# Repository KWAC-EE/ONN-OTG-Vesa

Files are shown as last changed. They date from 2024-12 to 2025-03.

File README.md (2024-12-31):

# ONN-OTG-Vesa
Powered Expansion Hub for the Walmart Onn TV Box


Outputs are saved into a ZIP folder, which can be uploaded directly to JLCPCB or PCBWay

PDFs are for reference to schematics and internal layers of the PCB

Hub should be assembled as standard 4-layer 1.6mm FR4 PCBA

Vesa may be FR4 or Aluminum (used for mounting hub to back of monitor)

C-to-Micro adapter is used to bridge Hub to Onn TV-Box (provides both power & data)

Hub linked to Vesa plate with 4x of 2108-440-AL-7 (https://www.digikey.com/short/th37r9zm) and 8x #4-40 screws

Onn TV box affixed to Hub PCBA with 5cm x 5cm velcro strips (for soft alignment of adapter)

Requires developer mode through Onn Android-tv system -> Default USB -> Ethernet to use peripherals

Updates to Android/Google TV have nerfed expandible storage, so SD card success may vary

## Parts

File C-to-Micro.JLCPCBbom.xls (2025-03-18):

Comment | Designator | Footprint | JLCPCB Part #
 | J1 | USB-309GD | C309337
0 | R1 | 0603 | C21189
 | J2 | ZX80-B-5SA(30) | C598212

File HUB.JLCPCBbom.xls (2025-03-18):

Comment | Designator | Footprint | JLCPCB Part #
0.01uF | C68 | 0603 | C57112
 | D1 | DO-214AC | C264107
 | J4 | TF-01A | C91145
10pF | C104,C102 | 0603 | C1634
47K | R18 | 0603 | C25819
680 | R11 | 0603 | C23228
 | J3 | 907-111A1022D10200 | C12049
0.1uF | C76,C75,C71,C70,C69,C41,C40,C39,C34,C33,C29,C28,C23,C20,C17,C16,C14,C11,C8,C6,C3,C2,C1 | 0603 | C14663
 | J5 | HR911105A | C12074
 | LED1 | 0603(1608Metric)Concave | C2286
54.9K | R5,R2 | 0603 | C23077
10uF | C19,C18,C10,C9,C5,C4 | 1206 | C13585
 | J2 | USB4110-GF-A | C2977718
 | TVS1 | DO-214AC | C435557
30 | R23,R4,R1 | 0603 | C2907026
 | L2,L1 | SMD8.2x8.6mm | C845060
2K | R37 | 0603 | C22975
 | L3 | TMPC0402HP | C357137
 | L7,L6,L5 | SMD-6-2CH | C396460
 | FB8 | 0603 | C127301
 | Y2 | ABM8G-25.000MHZ-B4Y-T | C9006
 | J1 | PJ-082BH | C3001296
 | U6,U2,U1 | TSOT-23-6 | C2071106
5.1K | R10,R8 | 0603 | C23186
 | U3 | SSOP-16-150mil | C284879
 | U4 | GL850G-HHY22 | C136617
 | SW1 | SMD-DPDT-SW | C2904912
 | FB4,FB1 | 1206 | C85841
20pF | C36,C35 | 0603 | C1648
30.9K | R25 | 0603 | C23022
 | U17 | RTL8152B-VB-CG | C50656
22uF | C22,C21,C15,C13,C12,C7 | 0603 | C59461
1uF | C38,C37,C32,C31,C30,C27,C26 | 0603 | C15849
 | U7 | 8-SOIC(0.209',5.30mmWIDTH) | C18192
10K | R30,R29,R28,R27,R26,R21,R20,R15,R7,R6 | 0603 | C25804
0 | R17 | 0603 | C21189
1K | R24,R9,R3 | 0603 | C21190
 | F4,F3 | 1206Fuse | C135339
100K | R19,R16,R14,R13,R12 | 0603 | C25803
 | U5 | SMD2520-4P | C655059

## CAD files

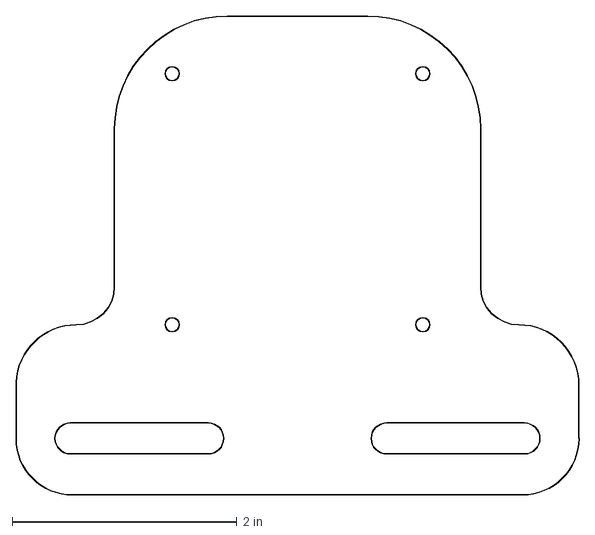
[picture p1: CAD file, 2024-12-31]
OTG_VESA.DXF
5.01 x 4.26 in

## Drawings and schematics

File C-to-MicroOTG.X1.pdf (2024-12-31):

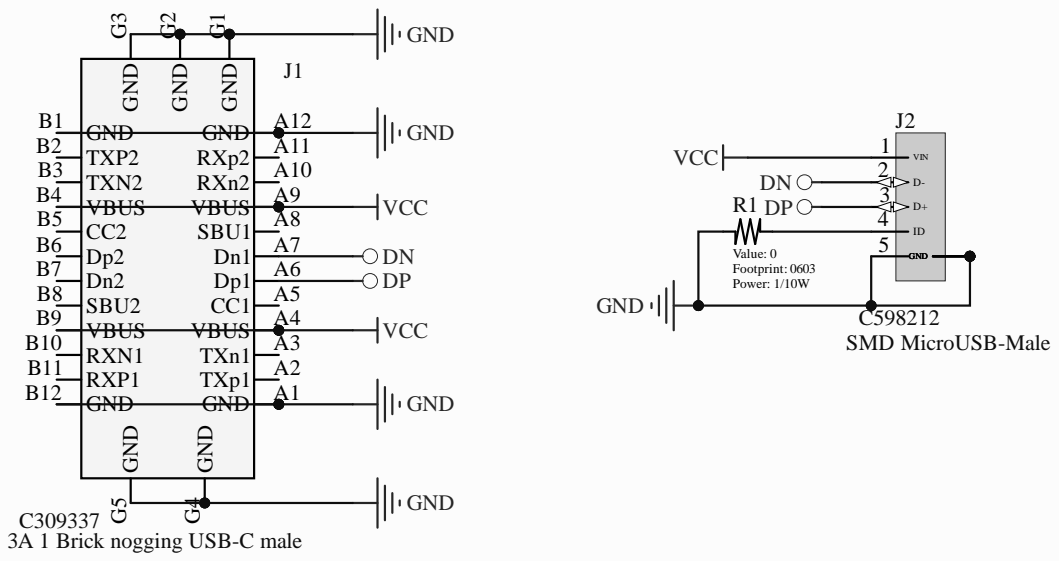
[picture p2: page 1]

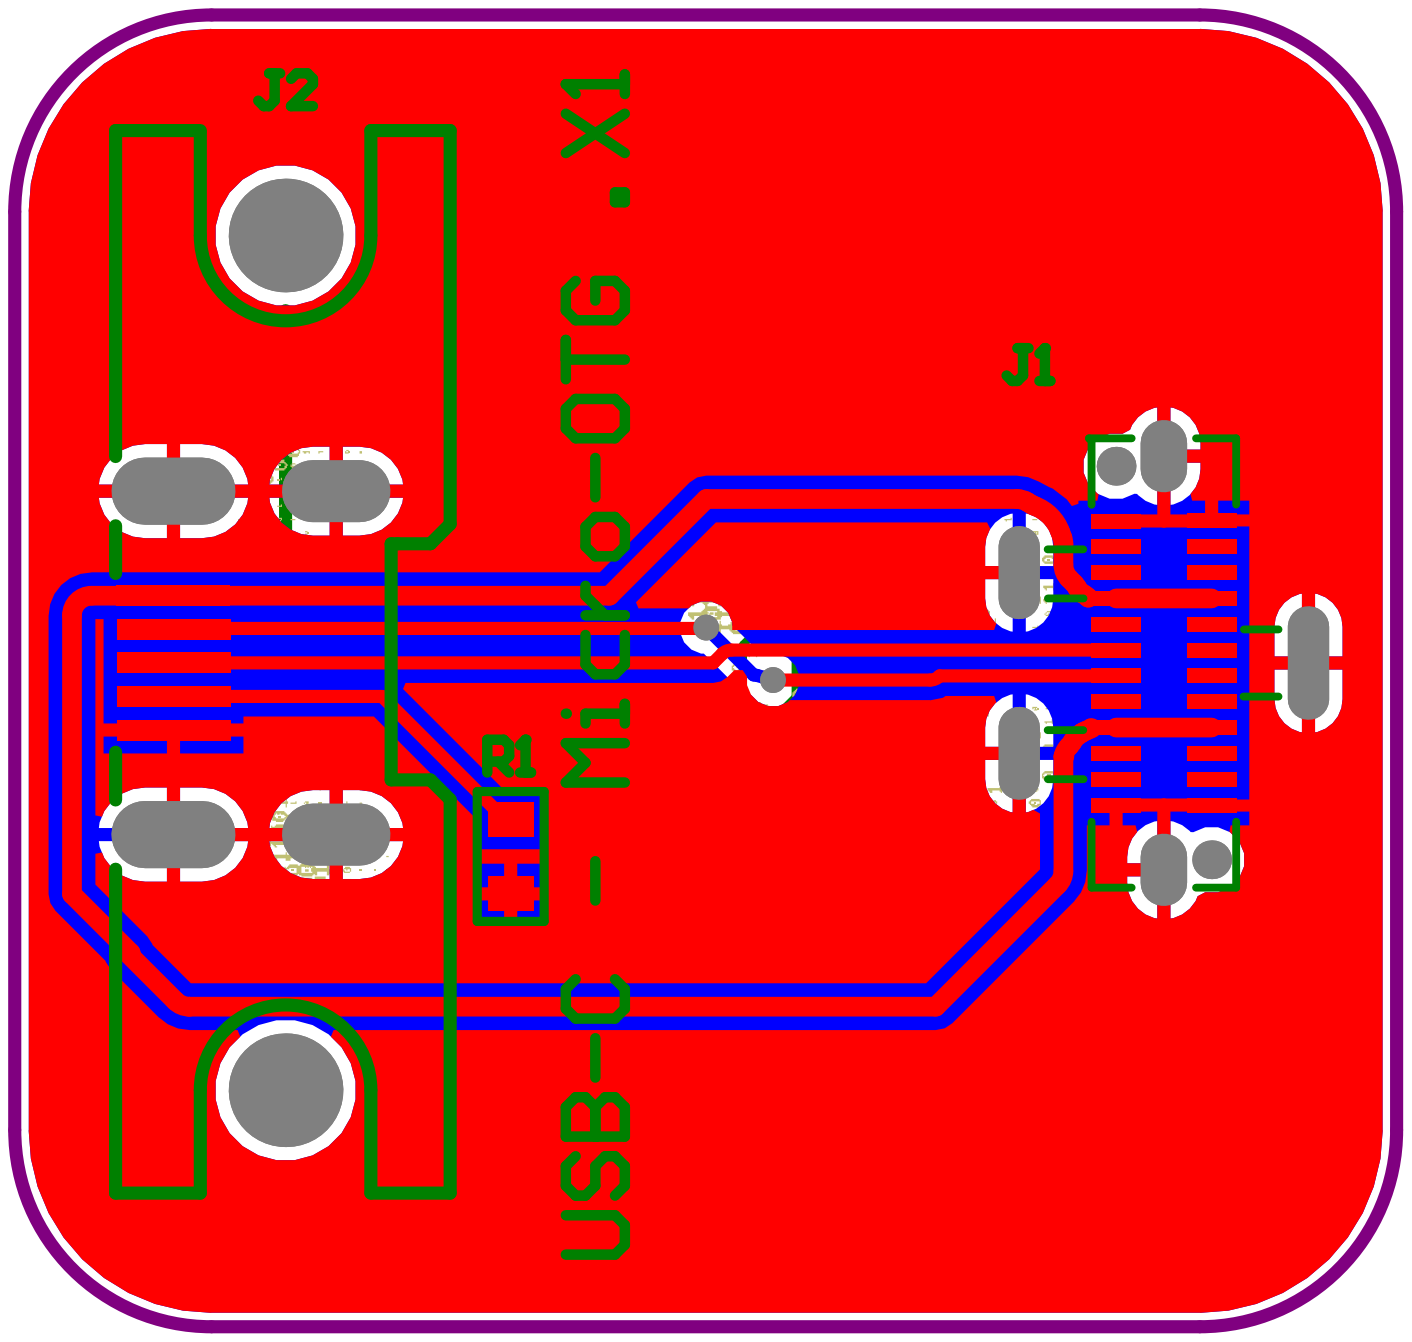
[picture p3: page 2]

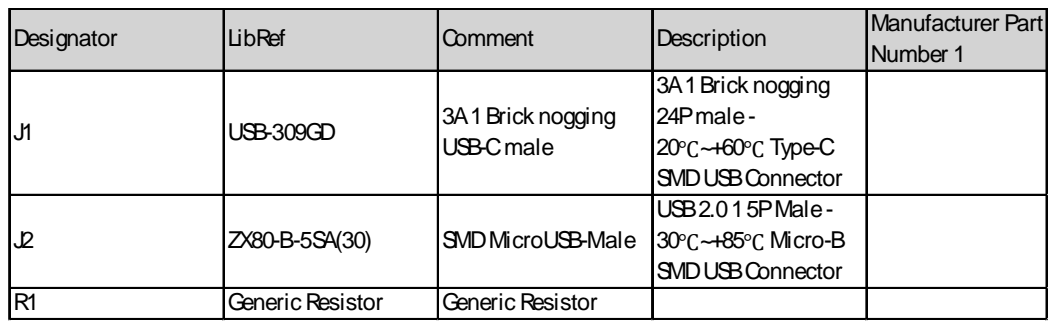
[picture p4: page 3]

Designator | LibRef | Comment | Description | Manufacturer Part Number 1

J1 | USB-309GD | 3A1Brick nogging USB-Cmale | 3A1Brick nogging 24Pmale-20℃~+60℃ Type-C SMDUSBConnector

J2 | ZX80-B-5SA(30) | SMDMicroUSB-Male | USB2.015PMale-30℃~+85℃ Micro-B SMDUSBConnector

R1 | Generic Resistor | Generic Resistor

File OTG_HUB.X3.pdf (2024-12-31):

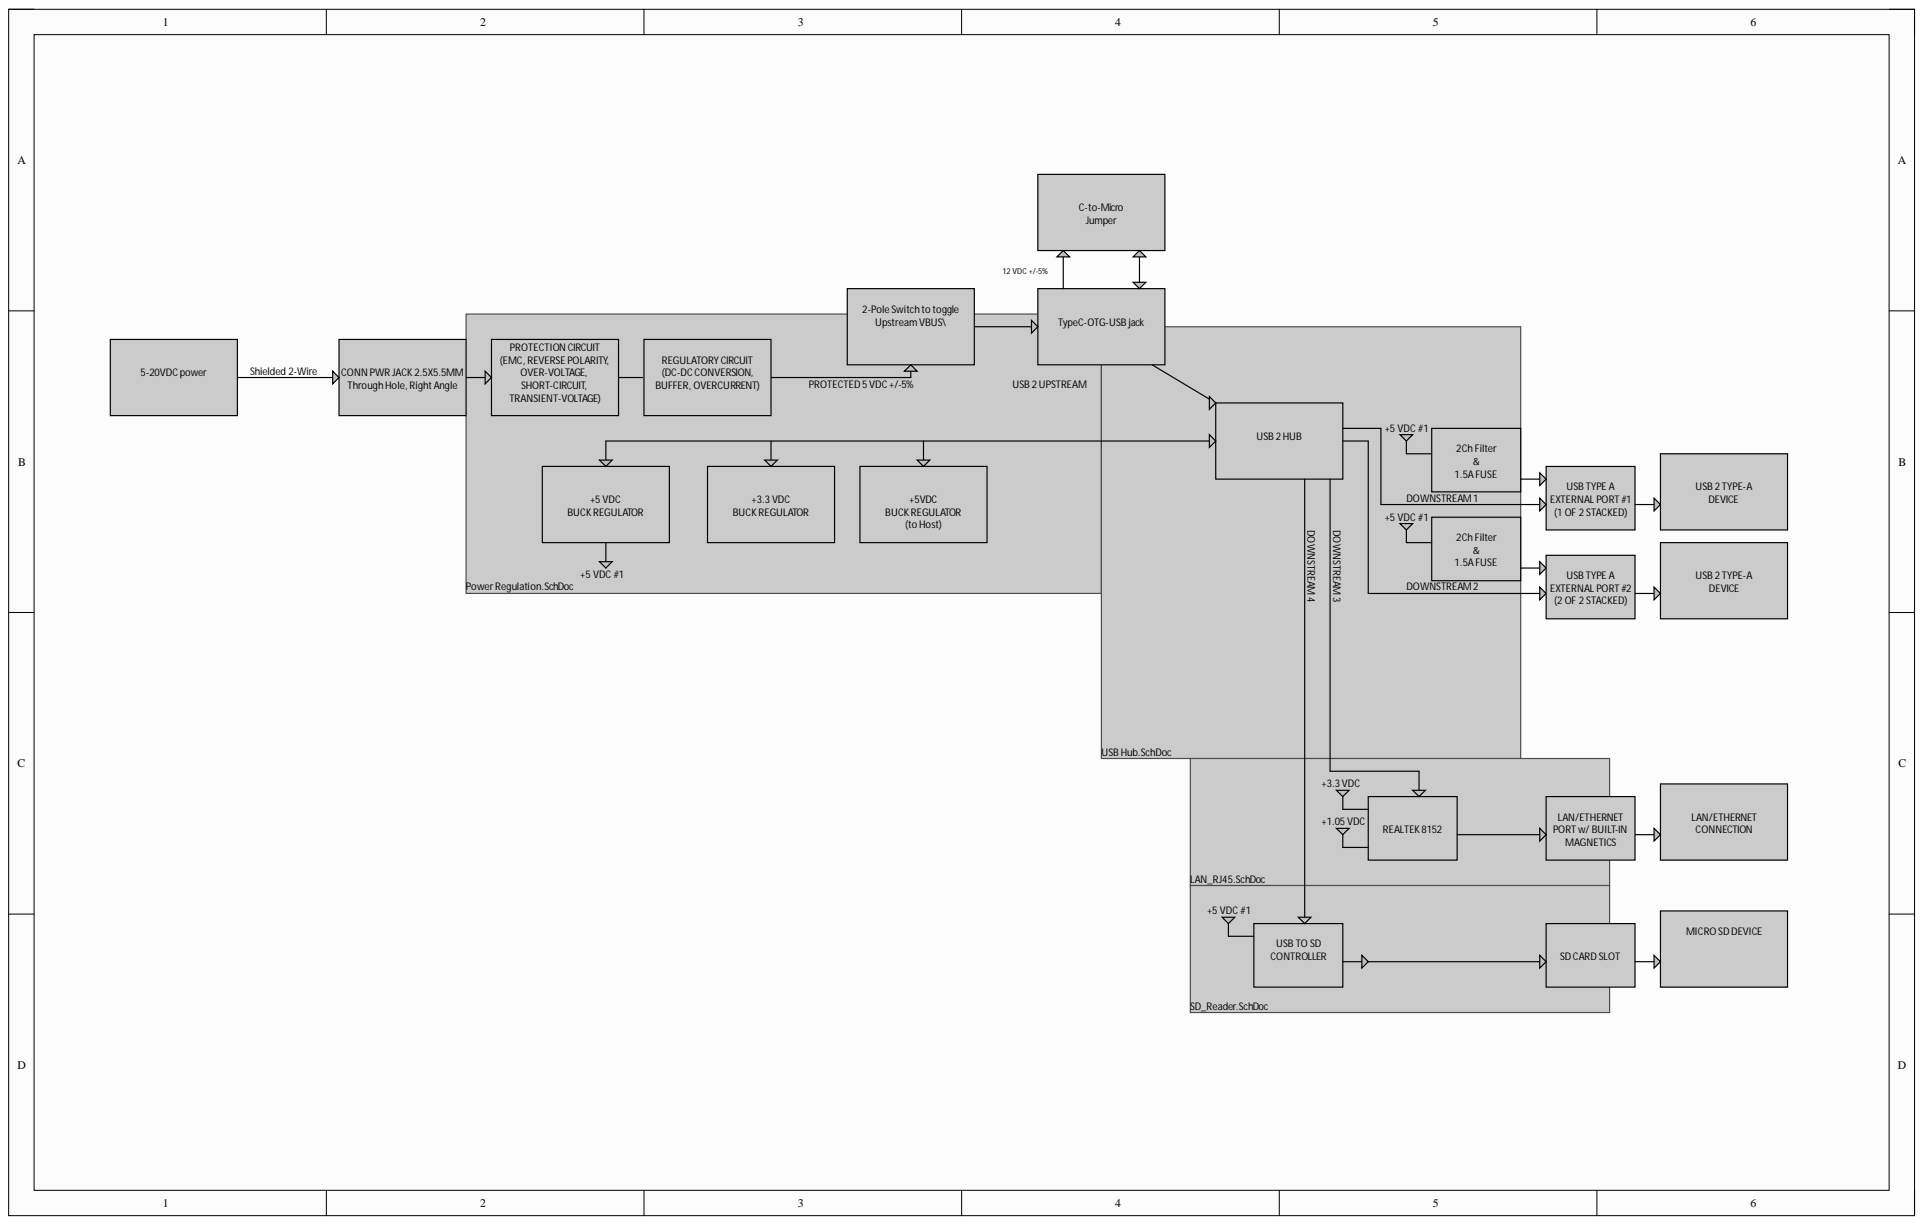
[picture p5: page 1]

2-Pole Switch to toggle
UpstreamVBUS\

TypeC-OTG-USB jack

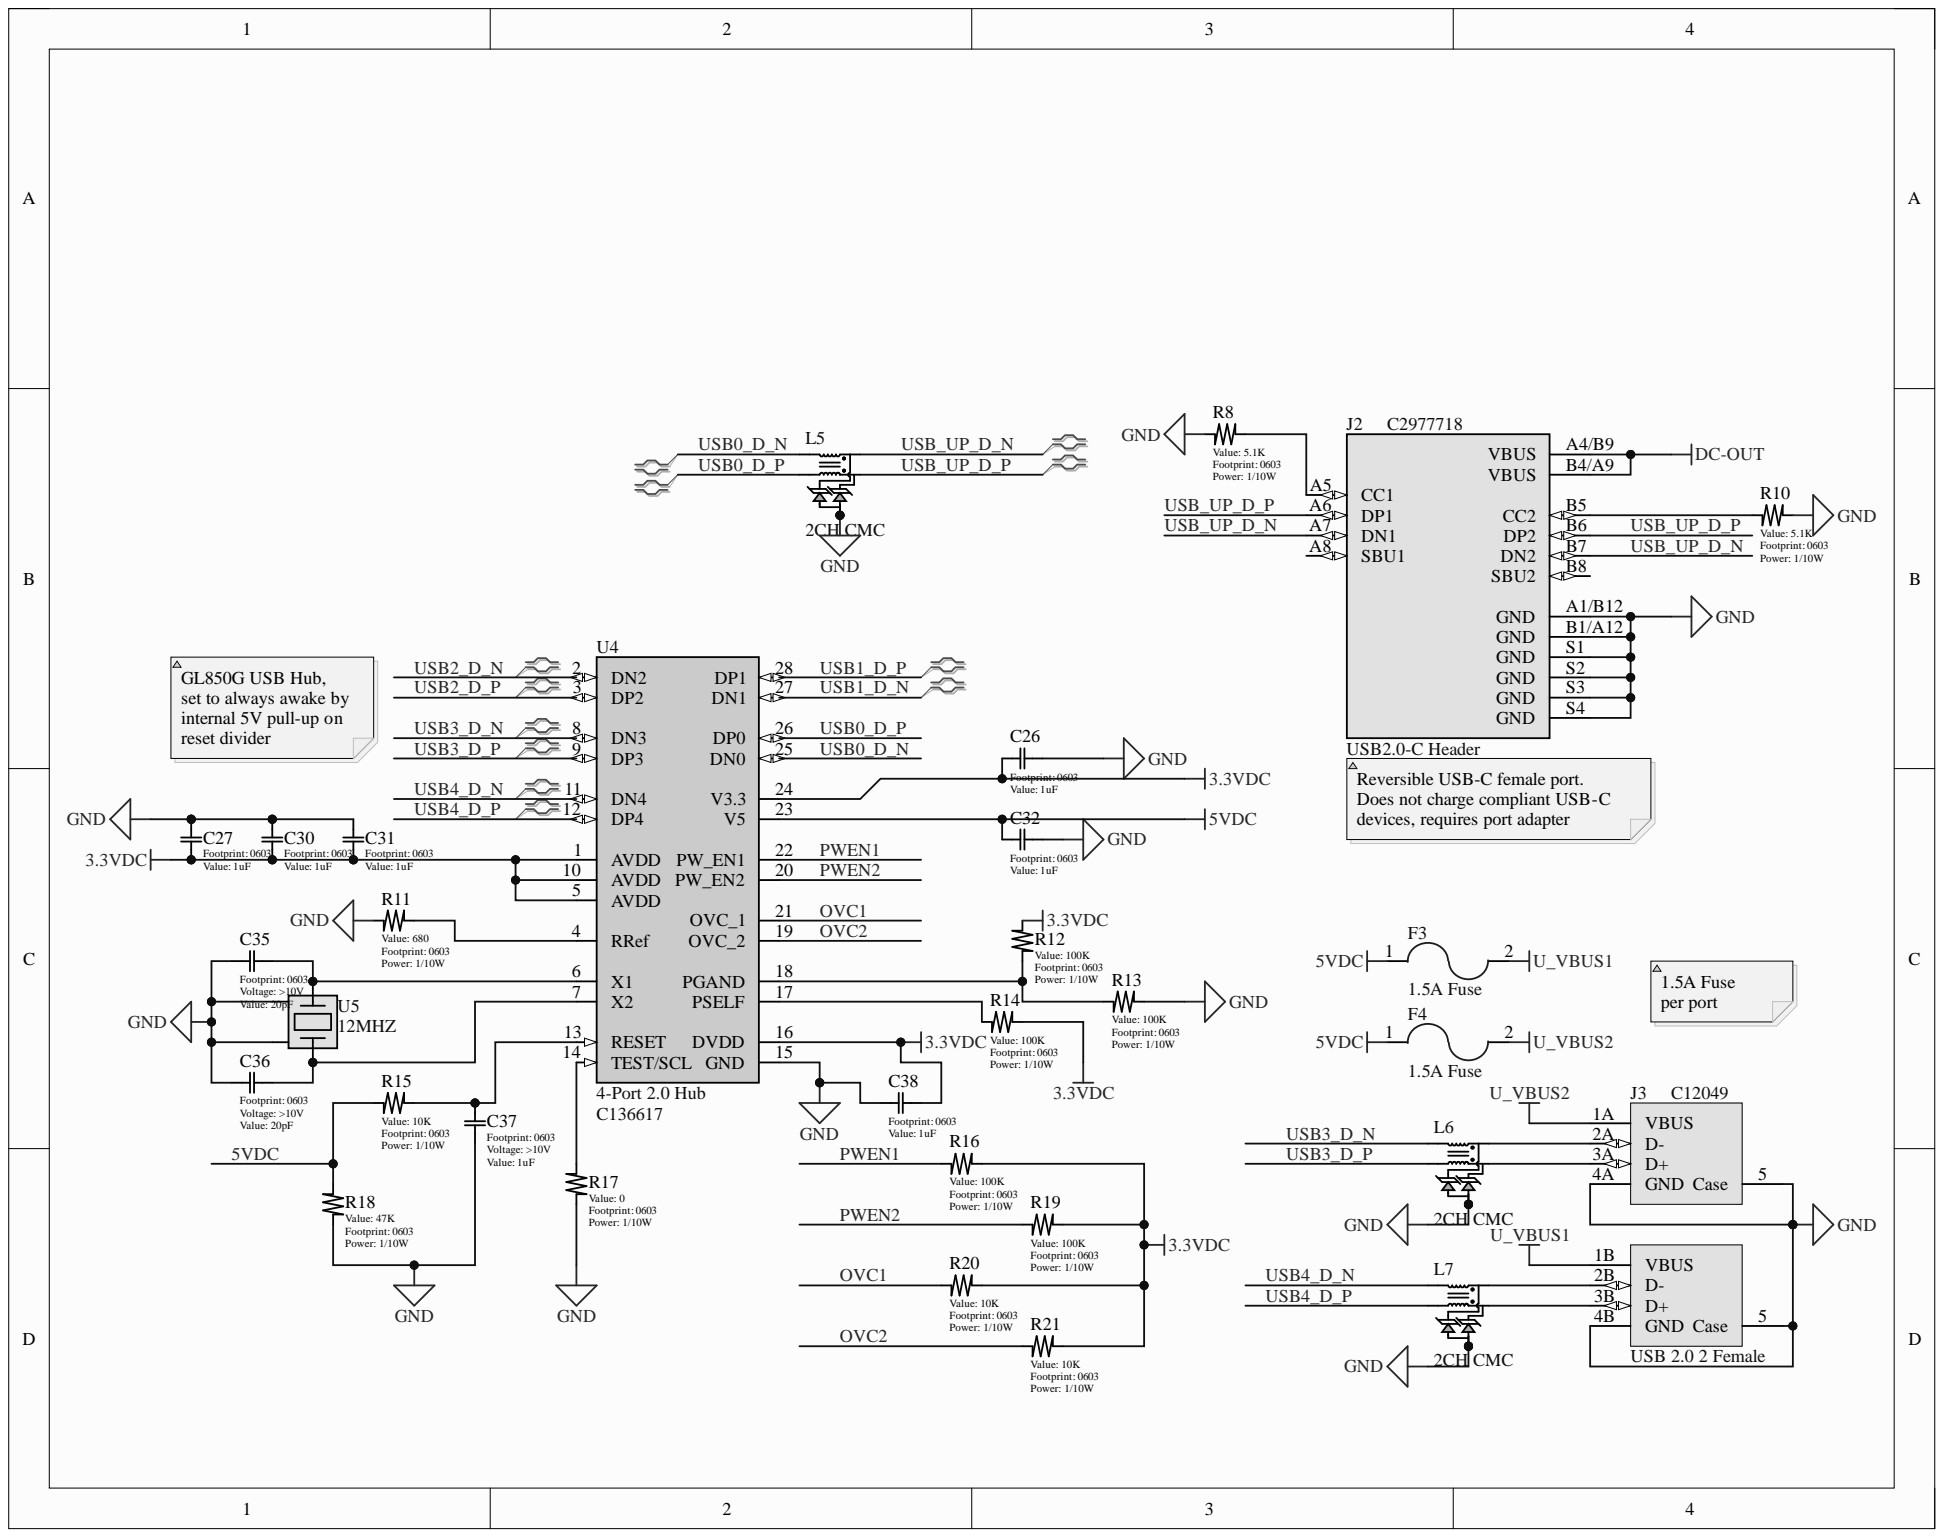
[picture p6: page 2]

GL850G USB Hub,
set to always awake by
internal 5V pull-up on
reset divider

USB2.0-C Header
Reversible USB-C female port.
Does not charge compliant USB-C
devices, requires port adapter

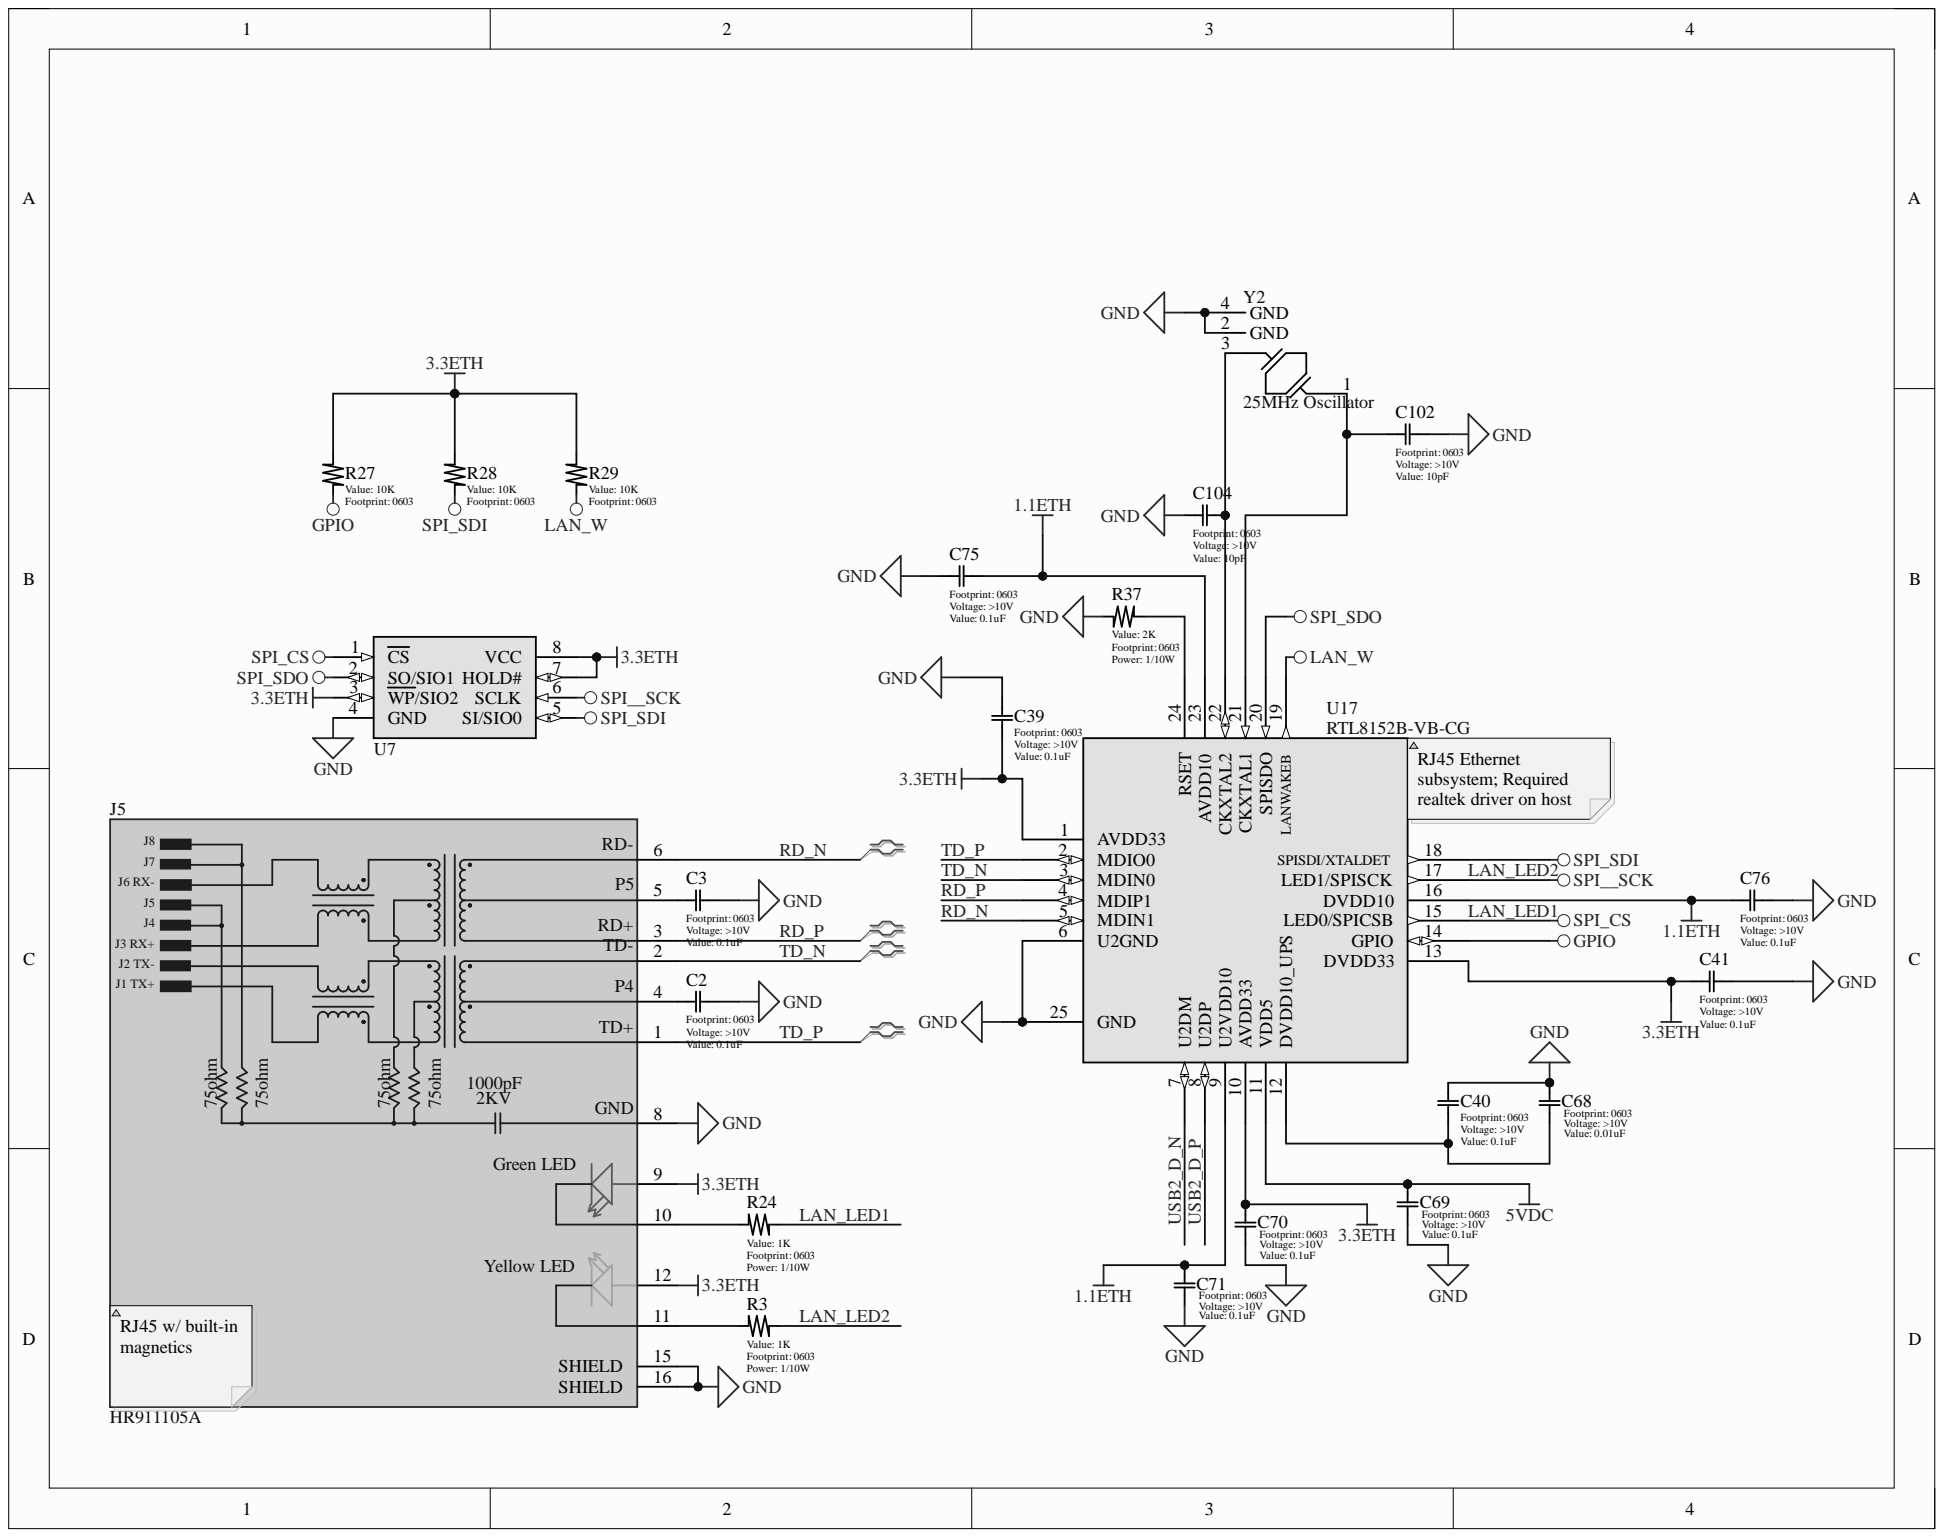
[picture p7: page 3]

RJ45 Ethernet
subsystem; Required
realtek driver on host

Voltage: >10V Value: 0.1uF

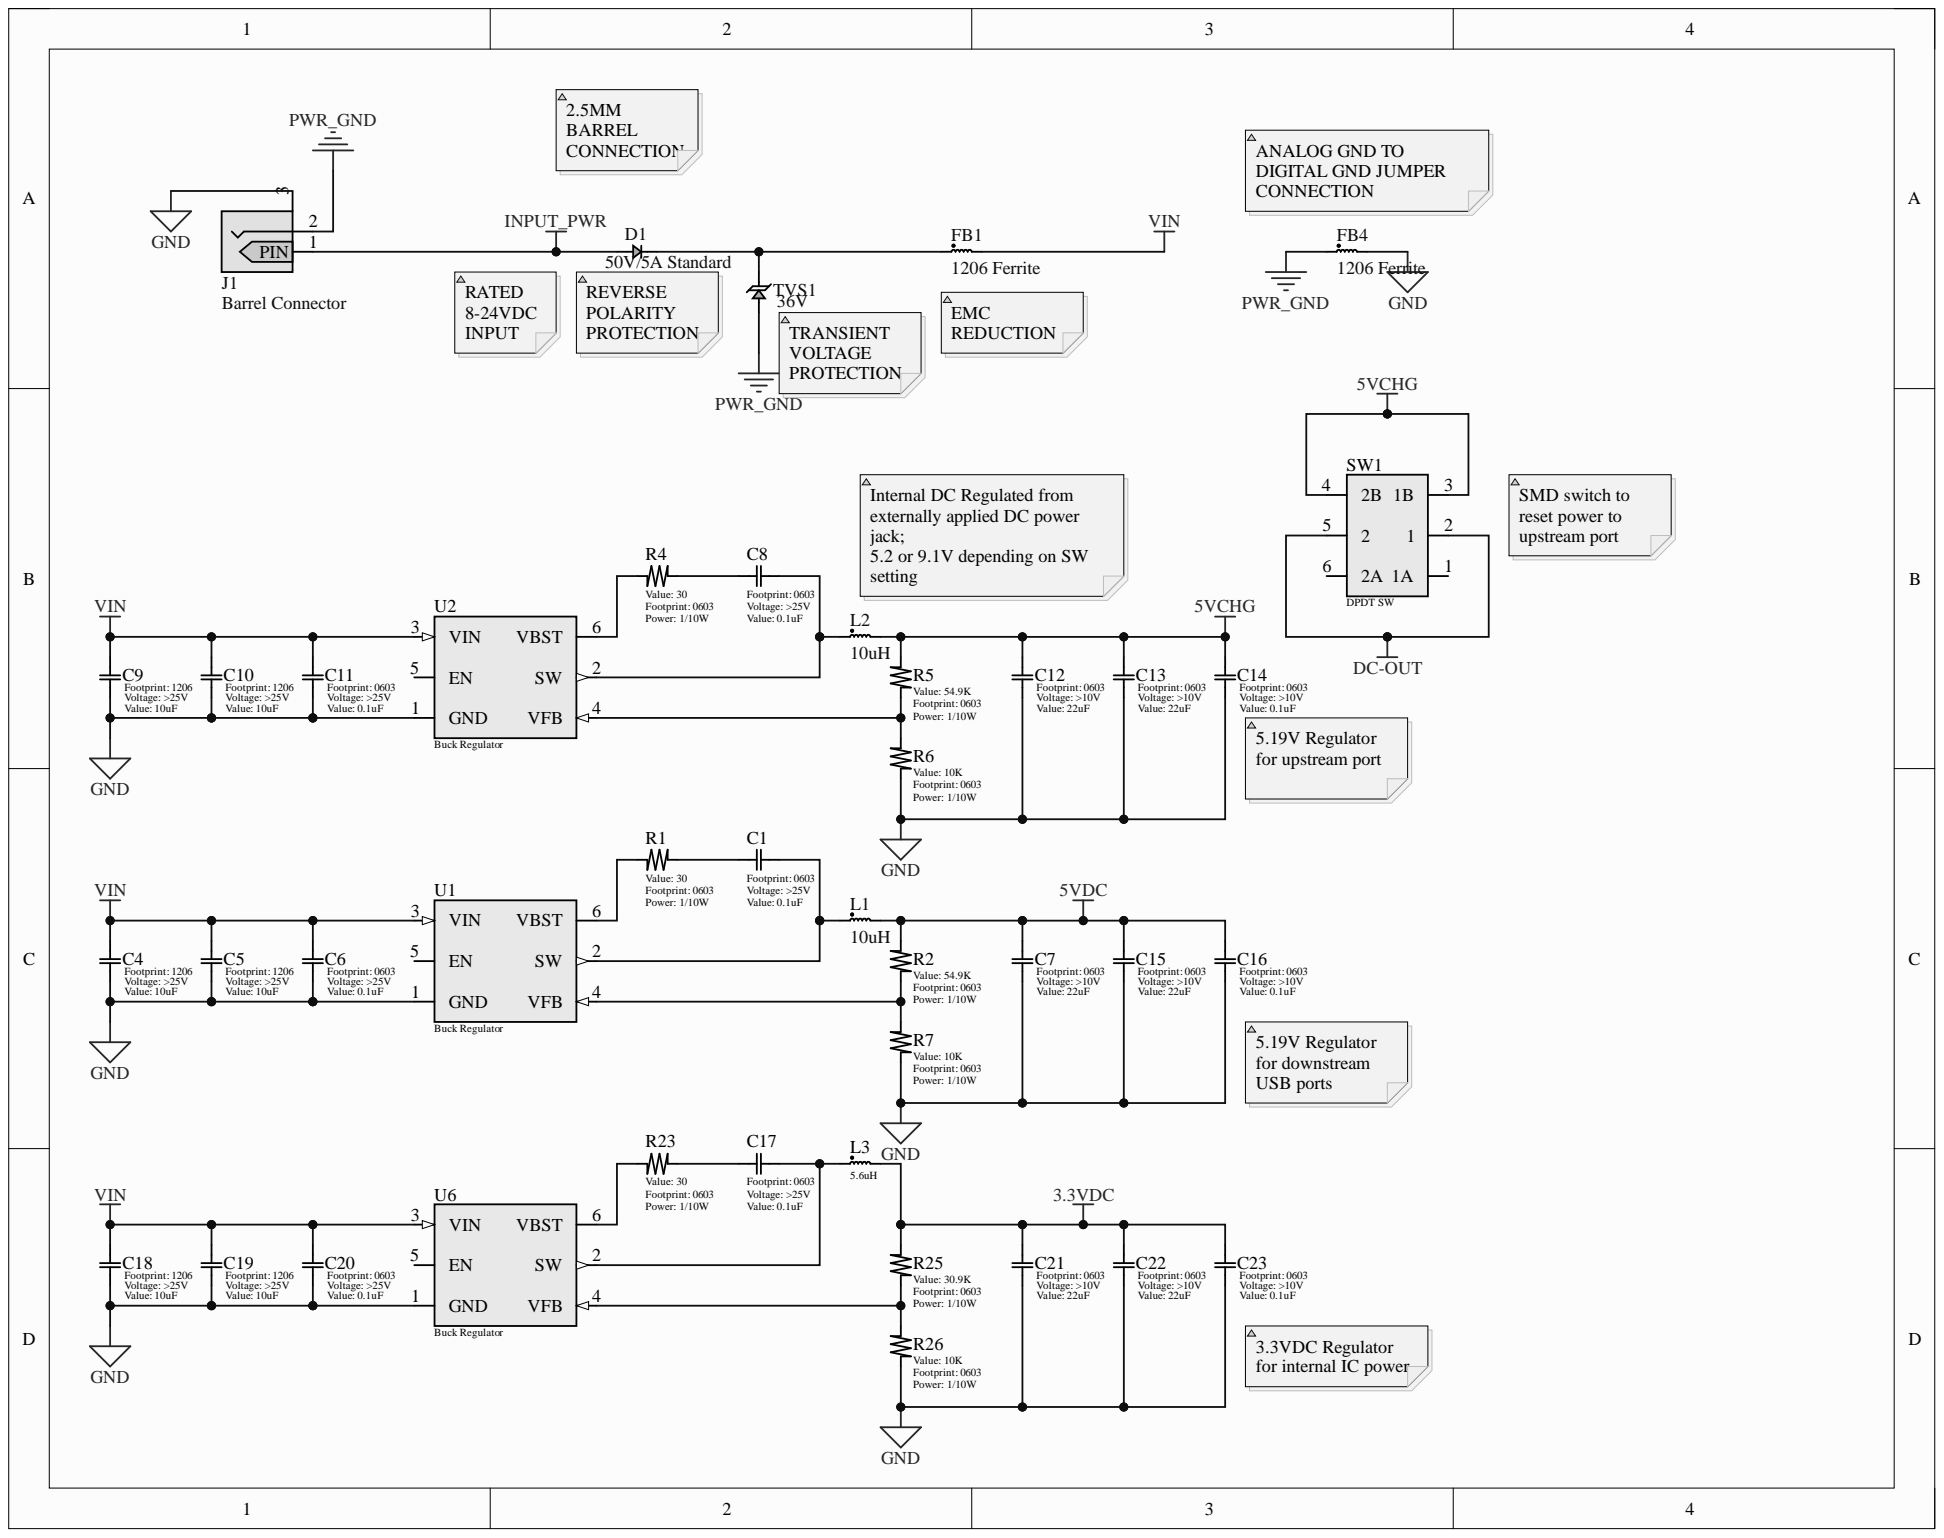
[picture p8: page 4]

Internal DC Regulated from
externally applied DC power
jack;
5.2 or 9.1V depending on SW
setting

DPDT SW 5VCHG | 1A | 1 2A 6

3.3VDC Regulator
for internal IC power

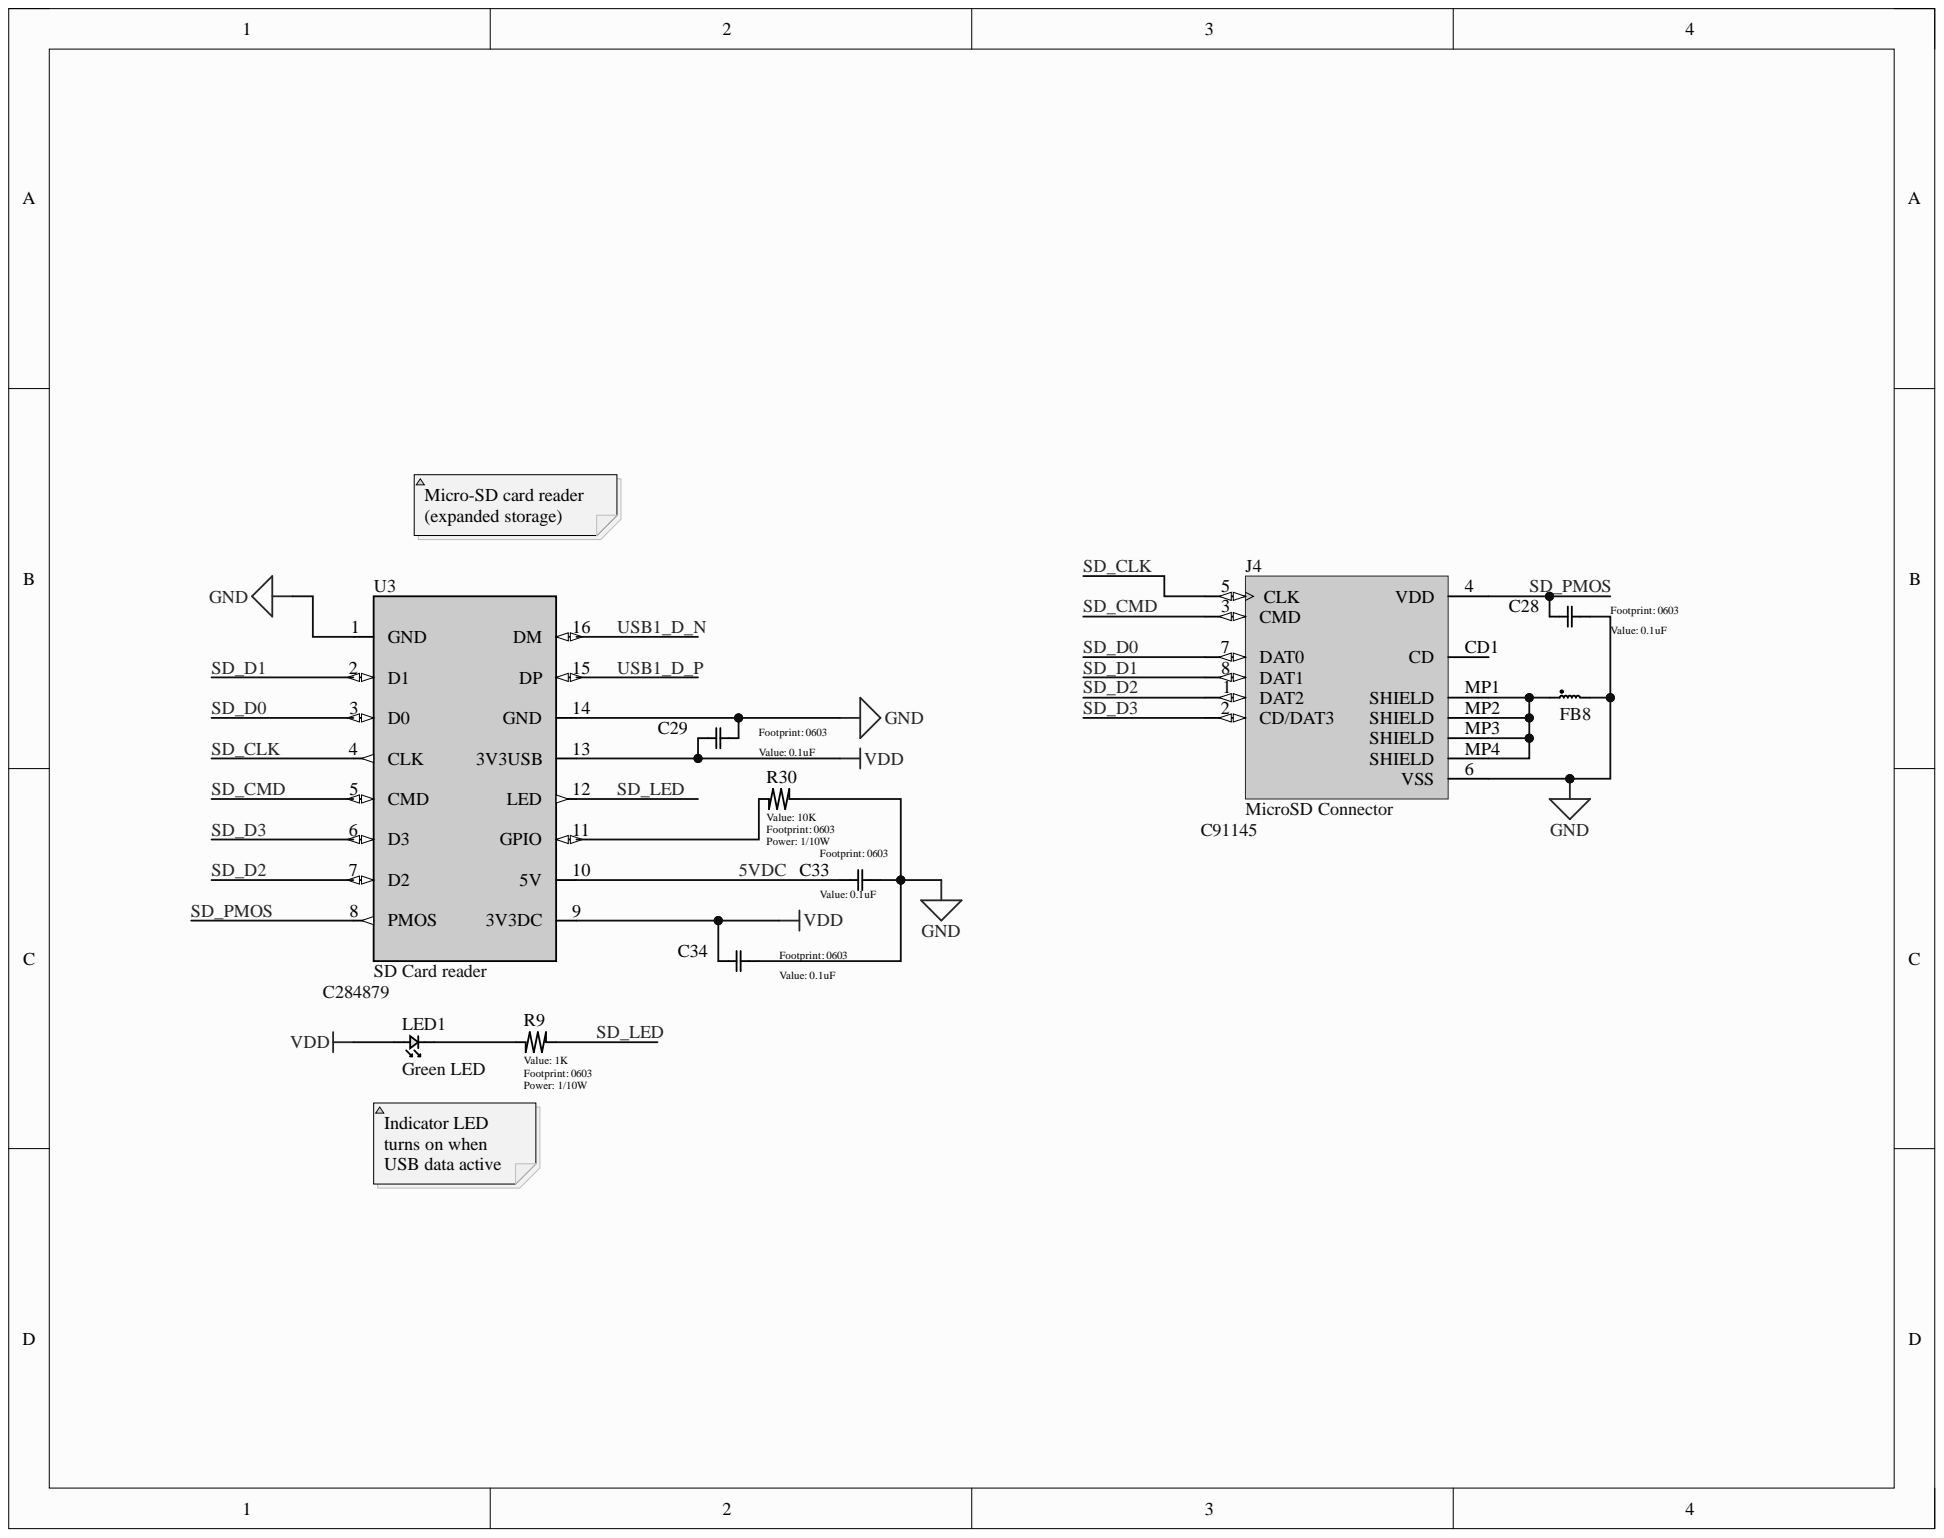
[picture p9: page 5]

9 | Value: 0.1u F

Footprin

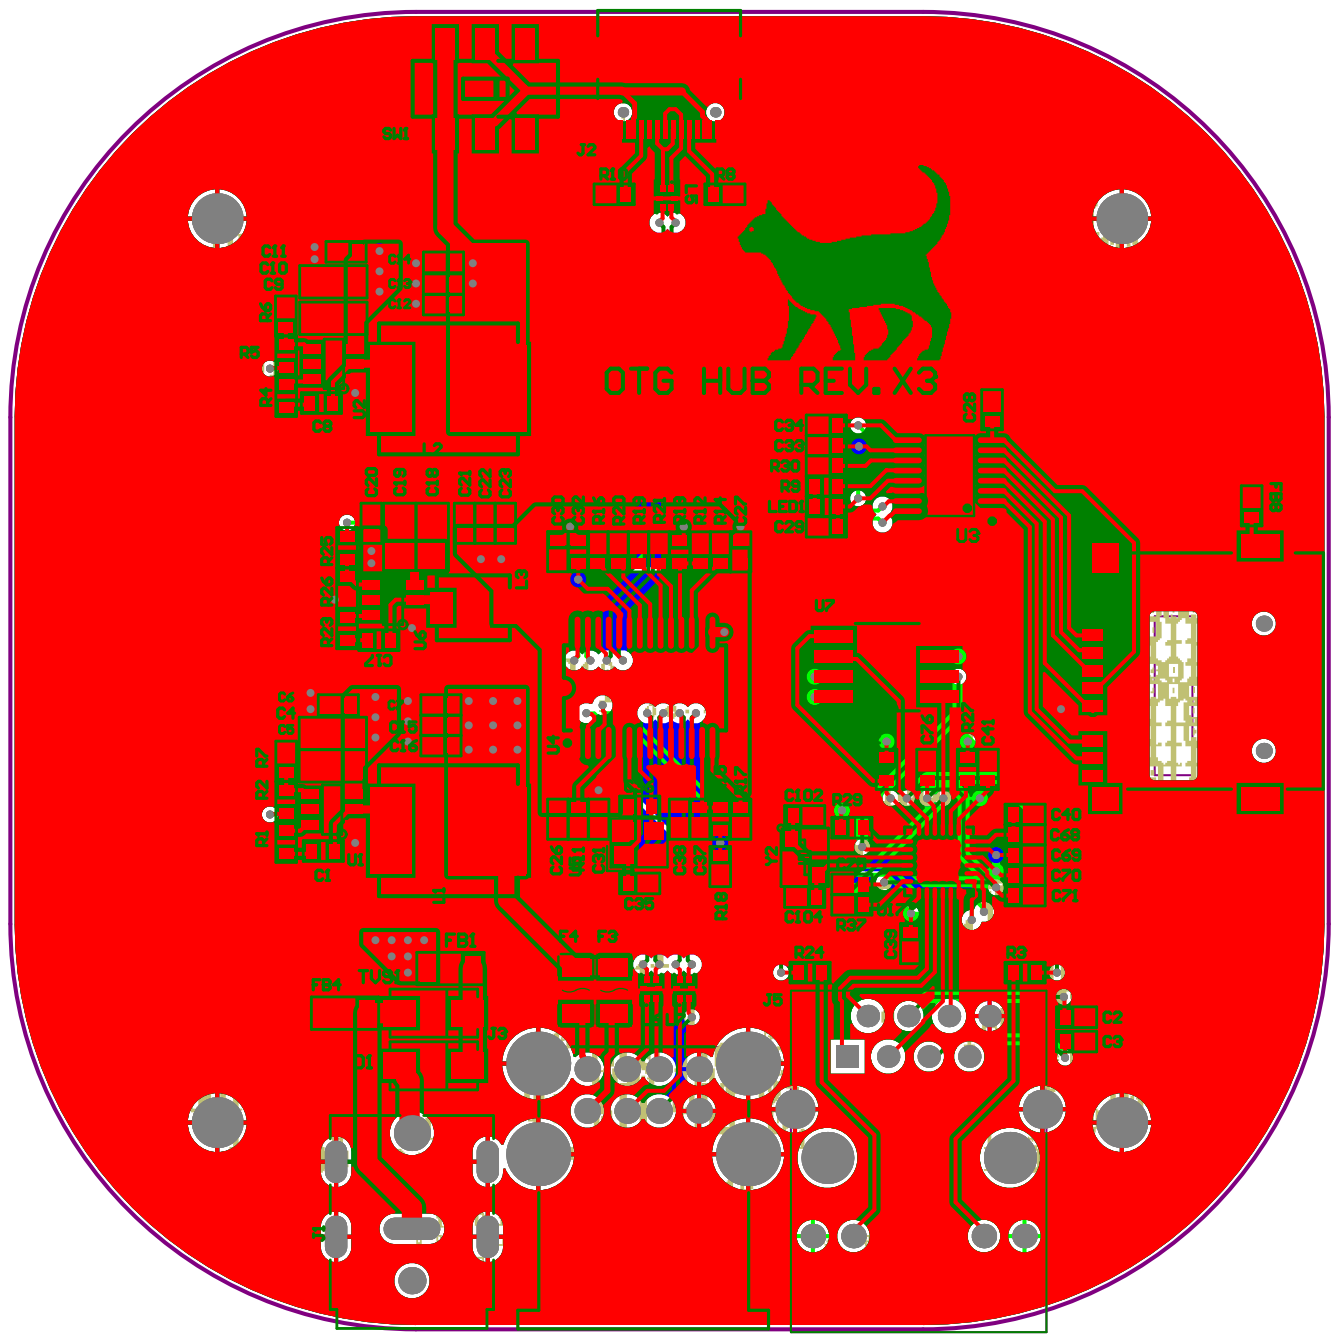
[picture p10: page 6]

Designator | LCSCPN | Footprint | Value | Description | Manufacturer Part Number
C1 | | 0603 | 0.1uF
C2 C3 | | 0603 0603 | 0.1uF 0.1uF
C4 C5 | 1206 1206 | 10uF 10uF
C6 | 0603 | 0.1uF
C7 C8 | 0603 0603 | 22uF 0.1uF
C9 | 1206 | 10uF
C10 C11 | 1206 0603 | 10uF 0.1uF
C12 | 0603 | 22uF
C13 C14 | 0603 0603 | 22uF 0.1uF
C15 | 0603 | 22uF
C16 C17 | 0603 0603 | 0.1uF 0.1uF
C18 C19 | 1206 1206 | 10uF 10uF
C20 | 0603 | 0.1uF
C21 C22 | 0603 0603 | 22uF 22uF
C23 | 0603 | 0.1uF
C26 C27 | 0603 0603 | 1uF 1uF
C28 | 0603 | 0.1uF
C29 C30 | 0603 0603 | 0.1uF 1uF
C31 | 0603 | 1uF
C33 C32 | 0603 0603 | 0.1uF 1uF
C34 C35 | 0603 0603 | 0.1uF 20pF
C36 | 0603 | 20pF
C37 C38 | 0603 0603 | 1uF 1uF
C39 | 0603 | 0.1uF
C40 C41 | 0603 0603 | 0.1uF 0.1uF
C68 | 0603 | 0.01uF
C69 C70 | 0603 0603 | 0.1uF 0.1uF
C71 C75 | | 0603 0603 | 0.1uF 0.1uF
C76 | | 0603 | 0.1uF
C102 C104 | | 0603 0603 | 10pF 10pF
D1 | | DO-214AC | | DiodeSuper Barrier 50V5A SurfaceMount
F3 | C135339 | 1206Fuse | | 6V750mA100A 600mW-40℃~+85℃ 1.5A 90mΩ200ms 500mΩ1206 ResettableFuses ROHS
F4 | C135339 | 1206Fuse | | 6V750mA100A 600mW-40℃~+85℃ 1.5A 90mΩ200ms 500mΩ1206 ResettableFuses ROHS
FB1 | C391193 | 1206 | | 160Ohms@ 100MHz1Power, Signal LineFerrite Bead 1206(3216 Metric) 6A 18mOhm
FB4 | C391193 | 1206 | | 160Ohms@ 100MHz1Power, Signal LineFerrite Bead 1206(3216 Metric) 6A 18mOhm
FB8 | C127301 | 0603 | | 120Ohms@100 MHz1Signal Line FerriteBead 0603 (1608Metric) 500mA180mOhm | PE-0603FB121ST
J1 | C3001296 | PJ-082BH | | CONN PWRJACK 2.5X5.5MM SOLDER
J2 | C2977718 | USB4110-GF-A | | USB-C(USBTYPE-C) USB2.0 Receptacle Connector 24 (16+8Dummy) Position Surface Mount, Right Angle; Through Hole
J3 | C12049 | 907-111A1022D10200 | | USB2.028 FemaleType-A Plugin USB Connectors ROHS
J4 | C91145 | TF-01A | | Deck MicroSD card (TFcard) Self bomb SMDSD Card Connector
J5 | C12074 | HR911105A | | RJ45Receptacle1 WithLEDPlugin Ethernet
L1 | C2051768 | SMD8.2x8.6mm | | 5.1A10uH±20% 5.2A- Power Inductor
L2 | C2051768 | SMD8.2x8.6mm | | 5.1A10uH±20% 5.2A- Power Inductor
L3 | C357137 | TMPC0402HP | | 2A5.6uH±20% SMDPower Inductor
L5 | C2903682 | SMD-6-2CH | | 35Ω@100MHz-40℃~+85℃ 4Ω5V 2100mASMD Common Mode Filters ROHS
L6 | C2903682 | SMD-6-2CH | | 35Ω@100MHz-40℃~+85℃ 4Ω5V 2100mASMD Common Mode Filters ROHS
L7 | C2903682 | SMD-6-2CH | | 35Ω@100MHz-40℃~+85℃ 4Ω5V 2100mASMD Common Mode Filters ROHS
LED1 | | 0603(1608Metric) Concave | | LEDUni-Color Green 574nm 2-Pin Chip LEDT/R
R1 | | 0603 | 30
R2 | | 0603 | 54.9K
R3 R4 | | 0603 0603 | 1K 30
R5 | | 0603 | 54.9K
R6 R7 | | 0603 0603 | 10K 10K
R8 | | 0603 | 5.1K
R9 R10 | | 0603 0603 | 1K 5.1K
R11 R12 | 0603 0603 | 680 100K
R13 | 0603 | 100K
R14 R15 | 0603 0603 | 100K 10K
R16 | 0603 | 100K
R17 R18 | 0603 0603 | 0 47K
R19 | 0603 | 100K
R20 R21 | 0603 0603 | 10K 10K
R23 | 0603 | 30
R24 R25 | 0603 0603 | 1K 30.9K
R26 R27 | | 0603 0603 | 10K 10K
R28 | | 0603 | 10K
R29 R30 | | 0603 0603 | 10K 10K
R37 | | 0603 | 2K
SW1 | C2904912 | SMD-DPDT-SW | | Brick nogging DPDTBlackSMD SlideSwitch
TVS1 | | DO-214AC | | 58.1VClamp 6.9A Ipp Tvs Diode SurfaceMount DO-214AC(SMA)
U1 | C2071106 | TSOT-23-6 | | BuckSwitching Regulator IC Positive Adjustable0.8V1 Output 3ASOT-23-6Thin, TSOT-23-6 | TPS56339DDCR
U2 | C2071106 | TSOT-23-6 | | BuckSwitching Regulator IC Positive Adjustable0.8V1 Output 3ASOT-23-6Thin, TSOT-23-6 | TPS56339DDCR
U3 | C284879 | SSOP-16-150mil | | USB2.0 SD/MSPROCard Reader Controller
U4 | C136617 | GL850G-HHY22 | | USB2.0Hub Controller
U5 | C655059 | SMD2520-4P | | 12MHzSMD Crystal Resonator 20pF±10ppm ±20ppm SMD2520-4PCrystals ROHS
U6 | C2071106 | TSOT-23-6 | | BuckSwitching Regulator IC Positive Adjustable0.8V1 Output 3ASOT-23-6Thin, TSOT-23-6 | TPS56339DDCR
U7 | C18192 | 8-SOIC(0.209", 5.30mm WIDTH) | | 16Mbit SPI SOIC-8-208mil NOR FLASH
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

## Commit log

2025-03-18 Add BOM for JLCPCB parts
    [JLCPCBbom.xls]
2025-03-18 Add BOM for C-to-Micro OTG adapter
    [C-to-Micro.JLCPCBbom.xls]
